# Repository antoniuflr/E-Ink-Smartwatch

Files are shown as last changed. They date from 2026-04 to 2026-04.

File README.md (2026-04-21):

# InkTime Smartwatch
The low-powered open-source e-paper watch.

## Final Assembly
<p align="center">
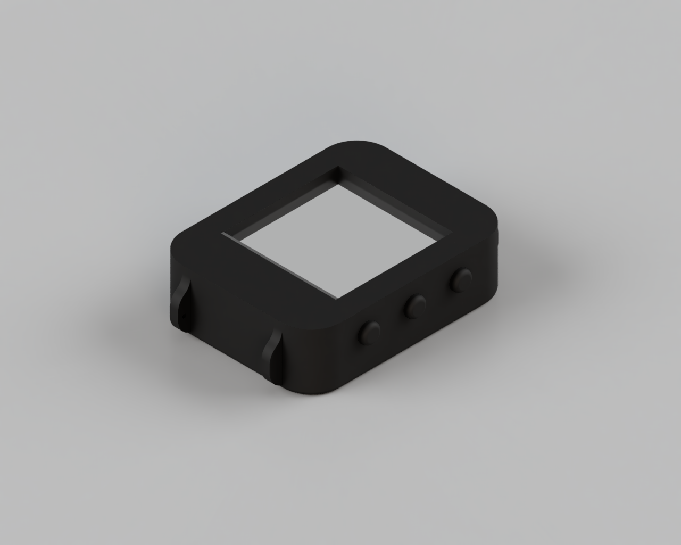
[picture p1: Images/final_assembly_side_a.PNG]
Final assembly side A
  
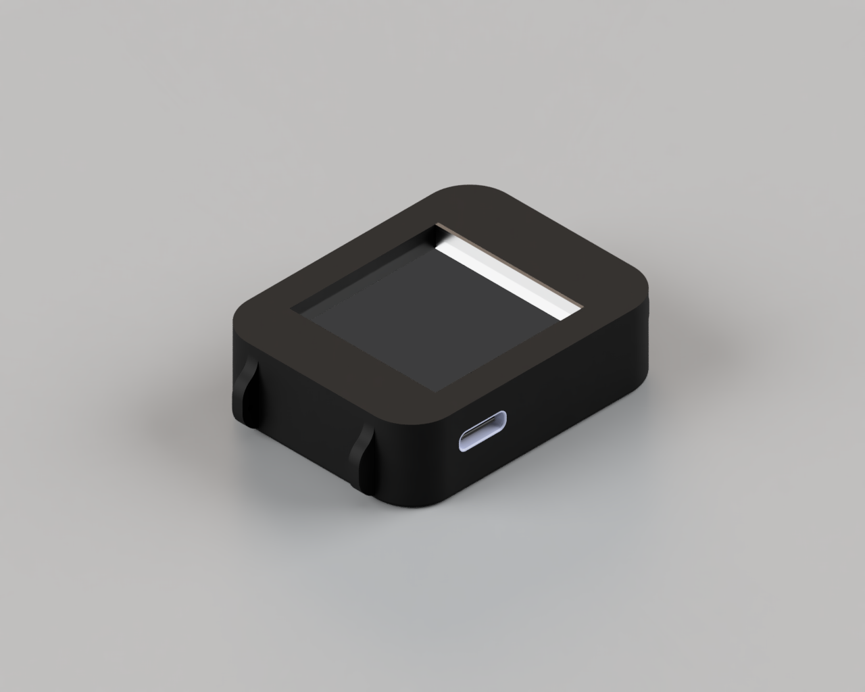
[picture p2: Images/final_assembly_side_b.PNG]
Final assembly side B
  
</p>

## Block Diagram
<p align="center">
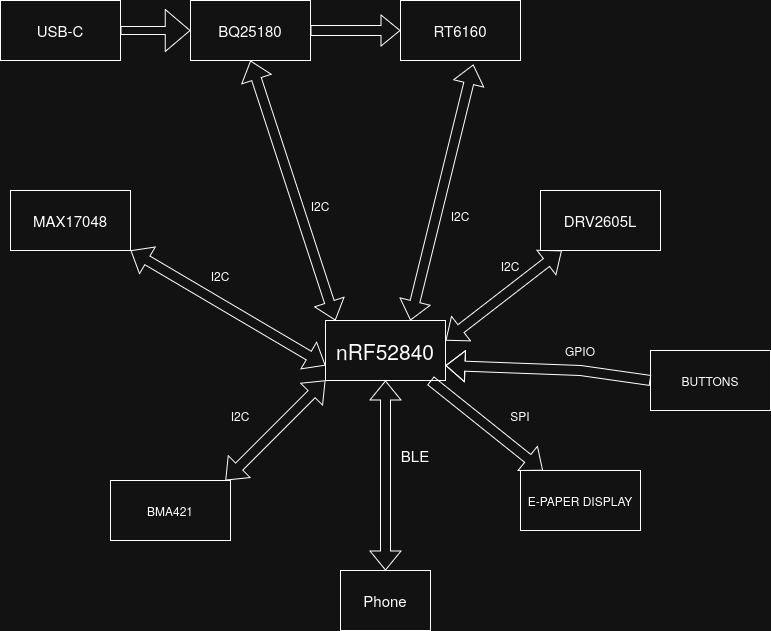
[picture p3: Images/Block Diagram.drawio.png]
InkTime block diagram
  
</p>

## Bill of Materials
| Ref | Componenta | Valoare | JLC Parts | Datasheet |
|-----|---|---|---|---|
| U1 | nRF52840 | $5.14 | [JLC](https://jlcpcb.com/parts/componentSearch?searchTxt=nRF52840-QF) | [DS](https://jlcpcb.com/api/file/downloadByFileSystemAccessId/8589839228197629952) |
| J1 | 503480-2400 | $0.84 | [JLC](https://jlcpcb.com/partdetail/MOLEX-5034802400/C122434) | [DS](https://www.molex.com/content/dam/molex/molex-dot-com/products/automated/en-us/salesdrawingpdf/503/503480/5034802400_sd.pdf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) |
| IC1 | BQ25180YBGR | $2.01 | [JLC](https://jlcpcb.com/partdetail/TexasInstruments-BQ25180YBGR/C3682423) | [DS](https://www.ti.com/cn/lit/gpn/bq25180) |
| X2 | FC-135_32.7680KA-A3 | $0.2677 | [JLC](https://jlcpcb.com/partdetail/SeikoEpson-FC_135_32_7680KAA3/C2650472) | [DS](https://jlcpcb.com/partdetail/SeikoEpson-FC_135_32_7680KAA3/C2650472) |
| Q1 | DMG2305UX-7 | $0.10 | [JLC](https://jlcpcb.com/partdetail/DiodesIncorporated-DMG2305UX7/C150470) | [DS](https://jlcpcb.com/api/file/downloadByFileSystemAccessId/8560079443617075200) |
| D5 | MBR0530 | $0.03 | [JLC](https://jlcpcb.com/partdetail/78464-MBR0530/C77336) | [DS](https://jlcpcb.com/api/file/downloadByFileSystemAccessId/8586175081181818880) |
| IC9 | RT6160 | $0.56 | [JLC](https://jlcpcb.com/partdetail/RichtekTech-RT6160AWSC/C7065276) | [DS](https://jlcpcb.com/api/file/downloadByFileSystemAccessId/8600398231234883584) |
| L2 | RC0402JR-070RL | $0.01 | [JLC](https://jlcpcb.com/partdetail/YAGEO-RC0402JR070RL/C60485) | [DS](https://jlcpcb.com/api/file/downloadByFileSystemAccessId/8717146932348461056) |
| J4 | KH-TYPE-C-16P | $0.08 | [JLC](https://jlcpcb.com/partdetail/Shenzhen_KinghelmElec-KH_TYPE_C16P/C709357) | [DS](https://jlcpcb.com/api/file/downloadByFileSystemAccessId/8588905154556923904) |
| SWD | TC2030-IDC | $100.26 | [JLC](https://jlcpcb.com/partdetail/MicrochipTech-TC2030_CLIP3PACK/C5444772) | [DS](https://www.lcsc.com/datasheet/lcsc_datasheet_2403201318_Microchip-Tech-TC2030-CLIP-3PACK_C5444772.pdf) |
| U3 | MAX17048G-T10 | $2.44 | [JLC](https://jlcpcb.com/partdetail/2777647-MAX17048GT10/C2682616) | [DS](https://jlcpcb.com/api/file/downloadByFileSystemAccessId/8588907428524003328) |
| D3 | USBLC6-2SC6Y | $0.24 | [JLC](https://jlcpcb.com/partdetail/STMicroelectronics-USBLC62SC6Y/C2969755) | [DS](https://jlcpcb.com/api/file/downloadByFileSystemAccessId/8603165824304111616) |
| L3 | RC0402JR-070RL | $0.01 | [JLC](https://jlcpcb.com/partdetail/YAGEO-RC0402JR070RL/C60485) | [DS](https://jlcpcb.com/api/file/downloadByFileSystemAccessId/8717146932348461056) |
| X1 | NX2016SA-32MHZ-EXS00A-CS11336 | $9.04 | [JLC](https://jlcpcb.com/partdetail/NDK-NX2016SA_32MHZ_EXS00ACS11336/C6134317) | [DS](https://jlcpcb.com/api/file/downloadByFileSystemAccessId/8603064888214908928) |
| ANT1 | 2450AT18B100E | $1.03 | [JLC](https://jlcpcb.com/partdetail/JohansonDielectrics-2450AT18B100E/C2917717) | [DS](https://jlcpcb.com/api/file/downloadByFileSystemAccessId/8588940948130156544) |
| Q3 | SI1308EDL-T1-GE3 | $0.18 | [JLC](https://jlcpcb.com/partdetail/VishayIntertech-SI1308EDL_T1GE3/C469327) | [DS](https://jlcpcb.com/api/file/downloadByFileSystemAccessId/8588884784742846464) |
| IC2 | DRV2605YZFR | $1.31 | [JLC](https://jlcpcb.com/partdetail/TexasInstruments-DRV2605YZFR/C81079) | [DS](https://www.ti.com/cn/lit/gpn/drv2605) |
| D2 | MBR0530 | $0.03 | [JLC](https://jlcpcb.com/partdetail/78464-MBR0530/C77336) | [DS](https://jlcpcb.com/api/file/downloadByFileSystemAccessId/8586175081181818880) |
| IC3 | BMA423 | $11.30 | [JLC](https://jlcpcb.com/partdetail/BoschSensortec-BMA423/C189517) | [DS](https://jlcpcb.com/api/file/downloadByFileSystemAccessId/8588894317147017216) |
| L7 | MLP2016SR47MT0S1 | $0.10 | [JLC](https://jlcpcb.com/partdetail/TDK-MLP2016SR47MT0S1/C87545) | [DS](https://jlcpcb.com/api/file/downloadByFileSystemAccessId/8588933367512879104) |
| L5 | 744043680 | $9.53 | [JLC](https://jlcpcb.com/partdetail/WurthElektronik-744043680/C2045671) | [DS](https://www.we-online.com/components/products/datasheet/744043680.pdf) |
| D4 | MBR0530 | $0.03 | [JLC](https://jlcpcb.com/partdetail/78464-MBR0530/C77336) | [DS](https://jlcpcb.com/api/file/downloadByFileSystemAccessId/8586175081181818880) |

## Hardware Overview
- `nRF52840 (U1)`: main MCU; handles BLE, USB, timekeeping, button logic, display refresh, and power-state control.
- `BQ25180 (IC1)`: LiPo charger and power-path manager; takes `VBUS` from USB-C, charges the battery, and exposes status on `I2C` plus `PMIC_INT`.
- `RT6160 (IC9)`: buck-boost regulator; converts the charger `SYS/VREG` rail into the stable `3V3` rail used by the digital system.
- `BMA421 IMU (IC3 schematic value)`: accelerometer/pedometer connected over `I2C`; `INT1` and `INT2` wake the MCU on motion and step events.
- `MAX17048 (U3)`: fuel gauge connected to raw `VBAT`; reports battery state over `I2C` and raises `ALERT` on low-battery thresholds.
- `DRV2605L (IC2)`: haptic driver on `I2C`; enabled by `HAPTIC_EN` and drives the vibration motor through `OUT+` and `OUT-`.
- `E-paper display (J1)`: connected through `SPI` (`SCK`, `MOSI`, `CS`) plus `DC`, `RST`, and `BUSY`; uses a dedicated switched rail so the panel can be fully turned off between updates.
- `USB-C + ESD (J4 + D3)`: provides `VBUS` power, USB `D+ / D-`, and surge protection for the MCU USB interface.
- `Debug + bring-up`: Tag-Connect `TC2030` exposes `SWDIO`, `SWDCLK`, and `RESET` for flashing and recovery.
- `Power strategy`: `USB-C 5V -> BQ25180 -> RT6160 -> 3V3`; the watch stays in low-power sleep most of the time, wakes on RTC/buttons/interrupts, and uses e-paper partial refreshes to keep average power low.
- `Communication`: shared `I2C` bus for PMIC, regulator, IMU, fuel gauge, and haptic driver; `SPI` for the display; `BLE` for the phone link.

## Exploded Assembly
<p align="center">
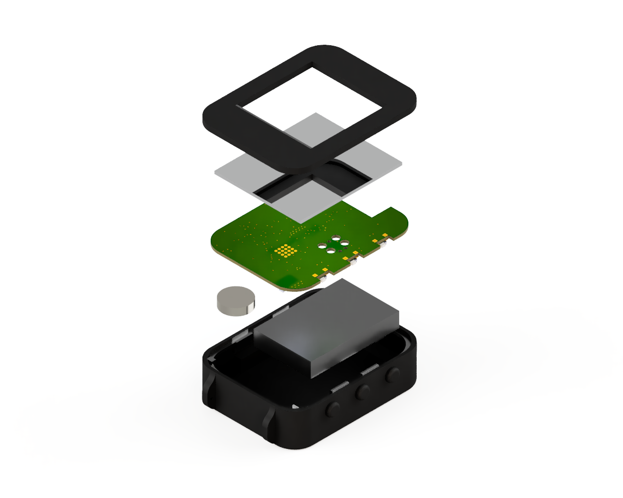
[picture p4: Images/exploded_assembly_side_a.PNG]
Exploded assembly side A
  
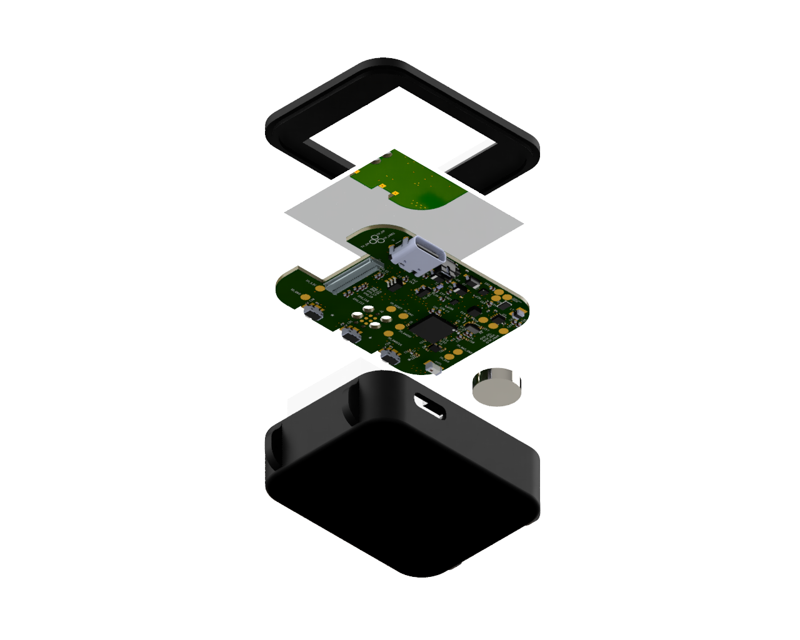
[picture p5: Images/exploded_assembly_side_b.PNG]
Exploded assembly side B
  
</p>

## nRF52840 Pin Mapping
| nRF52840 Pin | Signal | Component | Interface |
|---|---|---|---|
| P0.00/XL1 | XL1 | Crystal X2 (32.768kHz) | XTAL |
| P0.01/XL2 | XL2 | Crystal X2 (32.768kHz) | XTAL |
| P0.02/AIN0 | SCK | E-Paper (J1 FPC) | SPI SCK |
| P0.03/AIN1 | MOSI | E-Paper (J1 FPC) | SPI MOSI |
| P0.05/AIN3 | EPD_CS | E-Paper (J1 FPC) | SPI CS |
| P0.06 | SDA | BMA421, BQ25180, RT6160, MAX17048, DRV2605 | I2C SDA |
| P0.07 | SCL | BMA421, BQ25180, RT6160, MAX17048, DRV2605 | I2C SCL |
| P0.08 | IMU_INT1 | BMA421 | GPIO Input |
| P1.08 | IMU_INT2 | BMA421 | GPIO Input |
| P0.10/NFC2 | ALERT | MAX17048 | GPIO Input |
| P0.11 | PMIC_INT | BQ25180 | GPIO Input |
| P0.12 | HAPTIC_EN | DRV2605 | GPIO Output |
| P0.13 | SW_UP | Up button | GPIO Input |
| P0.14 | SW_ENT | Enter button | GPIO Input |
| P0.15 | EPD_DC | E-Paper (J1 FPC) | SPI DC |
| P0.16 | EPD_RST | E-Paper (J1 FPC) | GPIO Output |
| P0.17 | EPD_BUSY | E-Paper (J1 FPC) | GPIO Input |
| P0.18/RESET | RESET | TC2030-IDC | SWD / GPIO |
| P1.02 | SW_DN | Down button | GPIO Input |
| VBUS | VBUS | USB-C (J4) | Power |
| D- | D- | USB-C (J4) / USBLC6 | USB |
| D+ | D+ | USB-C (J4) / USBLC6 | USB |
| SWDCLK | SWDCLK | TC2030-IDC | SWD |
| SWDIO | SWDIO | TC2030-IDC | SWD |
| ANT | RF | 2450AT18B100E antenna | RF |

## PCB Views
<p align="center">
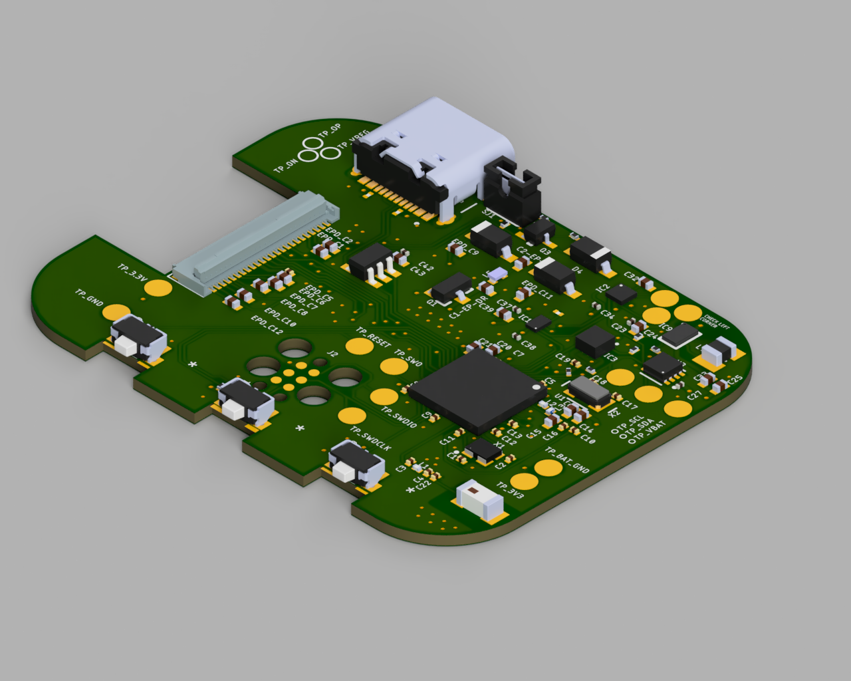
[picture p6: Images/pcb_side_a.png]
PCB side A
  
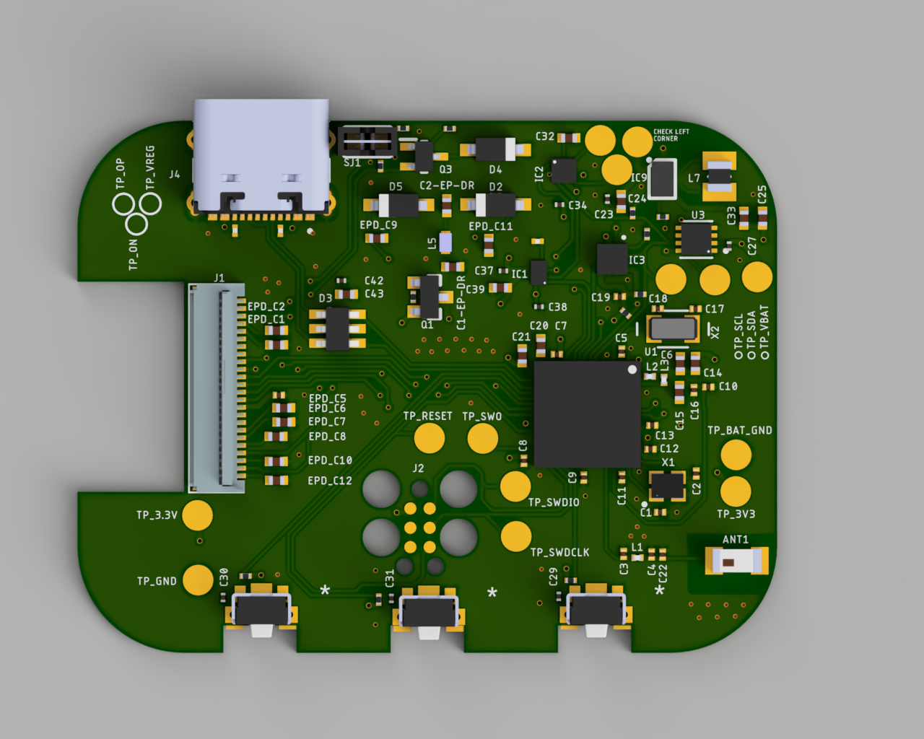
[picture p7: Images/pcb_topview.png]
PCB top view
  
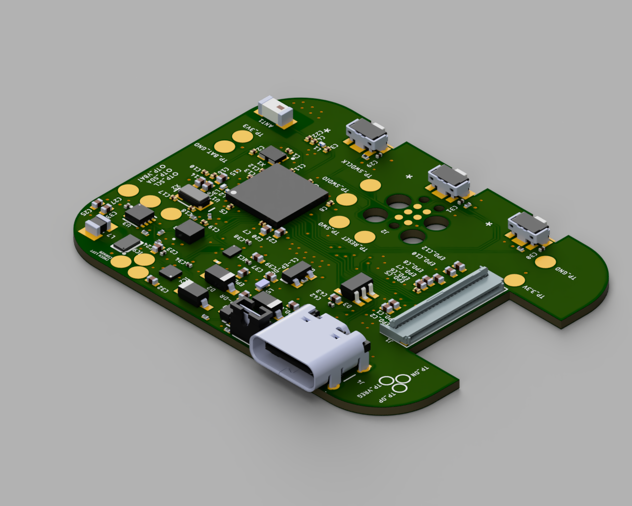
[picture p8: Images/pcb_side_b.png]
PCB side B
  
</p>

## Log Journal
- Grouping IC's with their respective passive components.
- Placing them so ratsnest is as straight as possible on the board.
- Route critical signal first.
- Route power.
- Route rest.

Clean ERC. Ignored micro-via errors in DRC because without them routing the BGA would have been impossible.

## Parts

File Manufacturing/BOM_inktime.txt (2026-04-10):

Partlist exported from Fusion Hub: chec   Project: InkTime  Board: inktime_schematic at 4/10/2026 11:14 PM

Qty Value                                                   Device                                                                       Package                                                                                                                Parts                                                                                                                      Description                                                                                                               ARROW_PART_NUMBER ARROW_PRICE-STOCK                                                                                AVAILABILITY CATEGORY CHECK_PRICES                                                                       COPYRIGHT                                                DATASHEET                                                 DESCRIPTION                                                                                                                                                                         DIGI-KEY_PART_NUMBER_1                    DIGI-KEY_PART_NUMBER_2 DIGI-KEY_PART_NUMBER_3                              FREQUENCY  FREQUENCY_STABILITY HEIGHT  JLCPCB LOAD_CAPACITANCE MANUFACTURER                                                     MANUFACTURER_NAME   MANUFACTURER_PART_NUMBER MF                 MOUSER_PART_NUMBER MOUSER_PRICE-STOCK                                                                                           MP                                                                                                       MPN                 OPERATING_TEMPERATURE PACKAGE                     PACKAGE_SIZE  PACKAGE_TYPE  PART_STATUS                  POPULARITY PRICE PROD_ID    PURCHASE-URL                                                                                                                               ROHS      SERIES SNAPEDA_LINK                                                                                                                                    SUBCATEGORY THERMALLOSS TOLERANCE                                                                           TP_SIGNAL_NAME TYPE       VALUE             
1                                                           ESP32_C6_LIBRARY_7_JUMPER_SJ                                                 ESP32_C6_LIBRARY_7_JUMPER_SJ                                                                                           SJ1                                                                                                                        SMD solder JUMPER                                                                                                                                                                                                                                                                                                                                                                                                                                                                                                                                                                                                                                                                                                                                                                                                                                                                                                                                                                                                                                                                                                                                                                                                                                                                                                                                         3                                                                                                                                                                                                                                                                                                                                                                                                                                                                                               
3   0                                                       CPF0201D7K68C1_CPF0201D7K68C1                                                CPF0201D7K68C1_0201                                                                                                    R2, R3, R4                                                                                                                 7.68k 0201 Thin Film Surface Mount Fixed Resistor +/-0.5% 0.031W CPF0201D7K68C1                                                                                                                                                                                                                                                                                                                                                                                                                                                                                                                                                                                                                                                                                                                                                                                                                                                                                                                                                                                                                                                                                                                                                                                                                                                                                                                                                                                                                                                                                                                                                                                                                                                                                                                                                                           
4   0.1µF                                                   GRM011R60J152KE01L_2_GRM011R60J152KE01L                                      GRM011R60J152KE01L_2_CAPC0201X13N                                                                                      C23, C27, C34, C42                                                                                                         Check availability                                                                                                                                                                                                                           In Stock              https://www.snapeda.com/parts/GRM011R60J152KE01L/Murata/view-part/?ref=eda                                                                                                                                                                                  SMD Capacitor X5R(EIA) with Capacitance: 1500pF Tol. 10%. Rated Voltage: 6.3Vdc                                                                                                                                                                                                                                                                                                                                                 Murata                                                                                                                                             GRM011R60J152KE01L                                                                                                                                 0201 Murata                                                                                     None                                                                                                                                                                         https://www.snapeda.com/parts/GRM011R60J152KE01L/Murata/view-part/?ref=snap                                                                                                                                                                                                                             
1   0.1µF/50v                                               NORDIC_NRF_3_CAPACITOR_0201_L                                                NORDIC_NRF_3_RESC0201_L                                                                                                EPD_C5                                                                                                                     Generic chip capacitor                                                                                                                                                                                                                                                                                                                                                                                                                                                                                                                                                                                                                                                                                                                                                                                                                                                                                                                                                                                                                                                                                                                                                                                                                                                                                                                                                                                                                                                                                                                                                                                                                                                                                                                                                                                                                                    
1   0.47                                                    CPF0201D7K68C1_CPF0201D7K68C1                                                CPF0201D7K68C1_0201                                                                                                    R1_EP_DR                                                                                                                   7.68k 0201 Thin Film Surface Mount Fixed Resistor +/-0.5% 0.031W CPF0201D7K68C1                                                                                                                                                                                                                                                                                                                                                                                                                                                                                                                                                                                                                                                                                                                                                                                                                                                                                                                                                                                                                                                                                                                                                                                                                                                                                                                                                                                                                                                                                                                                                                                                                                                                                                                                                                           
1   1.0µF                                                   NORDIC_NRF_3_CAPACITOR_0402_L                                                NORDIC_NRF_3_RESC0402_L                                                                                                C15                                                                                                                        Generic chip capacitor                                                                                                                                                                                                                                                                                                                                                                                                                                                                                                                                                                                                                                                                                                                                                                                                                                                                                                                                                                                                                                                                                                                                                                                                                                                                                                                                                                                                                                                                                                                                                                                                                                                                                                                                                                                                                                    
5   100nF                                                   NORDIC_NRF_3_CAPACITOR_0201_L                                                NORDIC_NRF_3_RESC0201_L                                                                                                C5, C7, C8, C12, C19                                                                                                       Generic chip capacitor                                                                                                                                                                                                                                                                                                                                                                                                                                                                                                                                                                                                                                                                                                                                                                                                                                                                                                                                                                                                                                                                                                                                                                                                                                                                                                                                                                                                                                                                                                                                                                                                                                                                                                                                                                                                                                    
1   100pF                                                   NORDIC_NRF_3_CAPACITOR_0201_L                                                NORDIC_NRF_3_RESC0201_L                                                                                                C11                                                                                                                        Generic chip capacitor                                                                                                                                                                                                                                                                                                                                                                                                                                                                                                                                                                                                                                                                                                                                                                                                                                                                                                                                                                                                                                                                                                                                                                                                                                                                                                                                                                                                                                                                                                                                                                                                                                                                                                                                                                                                                                    
2   10K                                                     CPF0201D7K68C1_CPF0201D7K68C1                                                CPF0201D7K68C1_0201                                                                                                    R2_EP_DR, R_PWR_EPD                                                                                                        7.68k 0201 Thin Film Surface Mount Fixed Resistor +/-0.5% 0.031W CPF0201D7K68C1                                                                                                                                                                                                                                                                                                                                                                                                                                                                                                                                                                                                                                                                                                                                                                                                                                                                                                                                                                                                                                                                                                                                                                                                                                                                                                                                                                                                                                                                                                                                                                                                                                                                                                                                                                           
1   10K                                                     ERA-1AEB3401C_CPF0201D7K68C1                                                 ERA-1AEB3401C_0201                                                                                                     R9                                                                                                                         7.68k 0201 Thin Film Surface Mount Fixed Resistor +/-0.5% 0.031W CPF0201D7K68C1                                                                                                                                                                                                                                                                                                                                                                                                                                                                                                                                                                                                                                                                                                                                                                                                                                                                                                                                                                                                                                                                                                                                                                                                                                                                                                                                                                                                                                                                                                                                                                                                                                                                                                                                                                           
3   10k                                                     CPF0201D7K68C1_CPF0201D7K68C1                                                CPF0201D7K68C1_0201                                                                                                    R5, R7, R8                                                                                                                 7.68k 0201 Thin Film Surface Mount Fixed Resistor +/-0.5% 0.031W CPF0201D7K68C1                                                                                                                                                                                                                                                                                                                                                                                                                                                                                                                                                                                                                                                                                                                                                                                                                                                                                                                                                                                                                                                                                                                                                                                                                                                                                                                                                                                                                                                                                                                                                                                                                                                                                                                                                                           
3   10µF                                                    NORDIC_NRF_3_CAPACITOR_0402_L                                                NORDIC_NRF_3_RESC0402_L                                                                                                C1-EP-DR, C24, C39                                                                                                         Generic chip capacitor
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

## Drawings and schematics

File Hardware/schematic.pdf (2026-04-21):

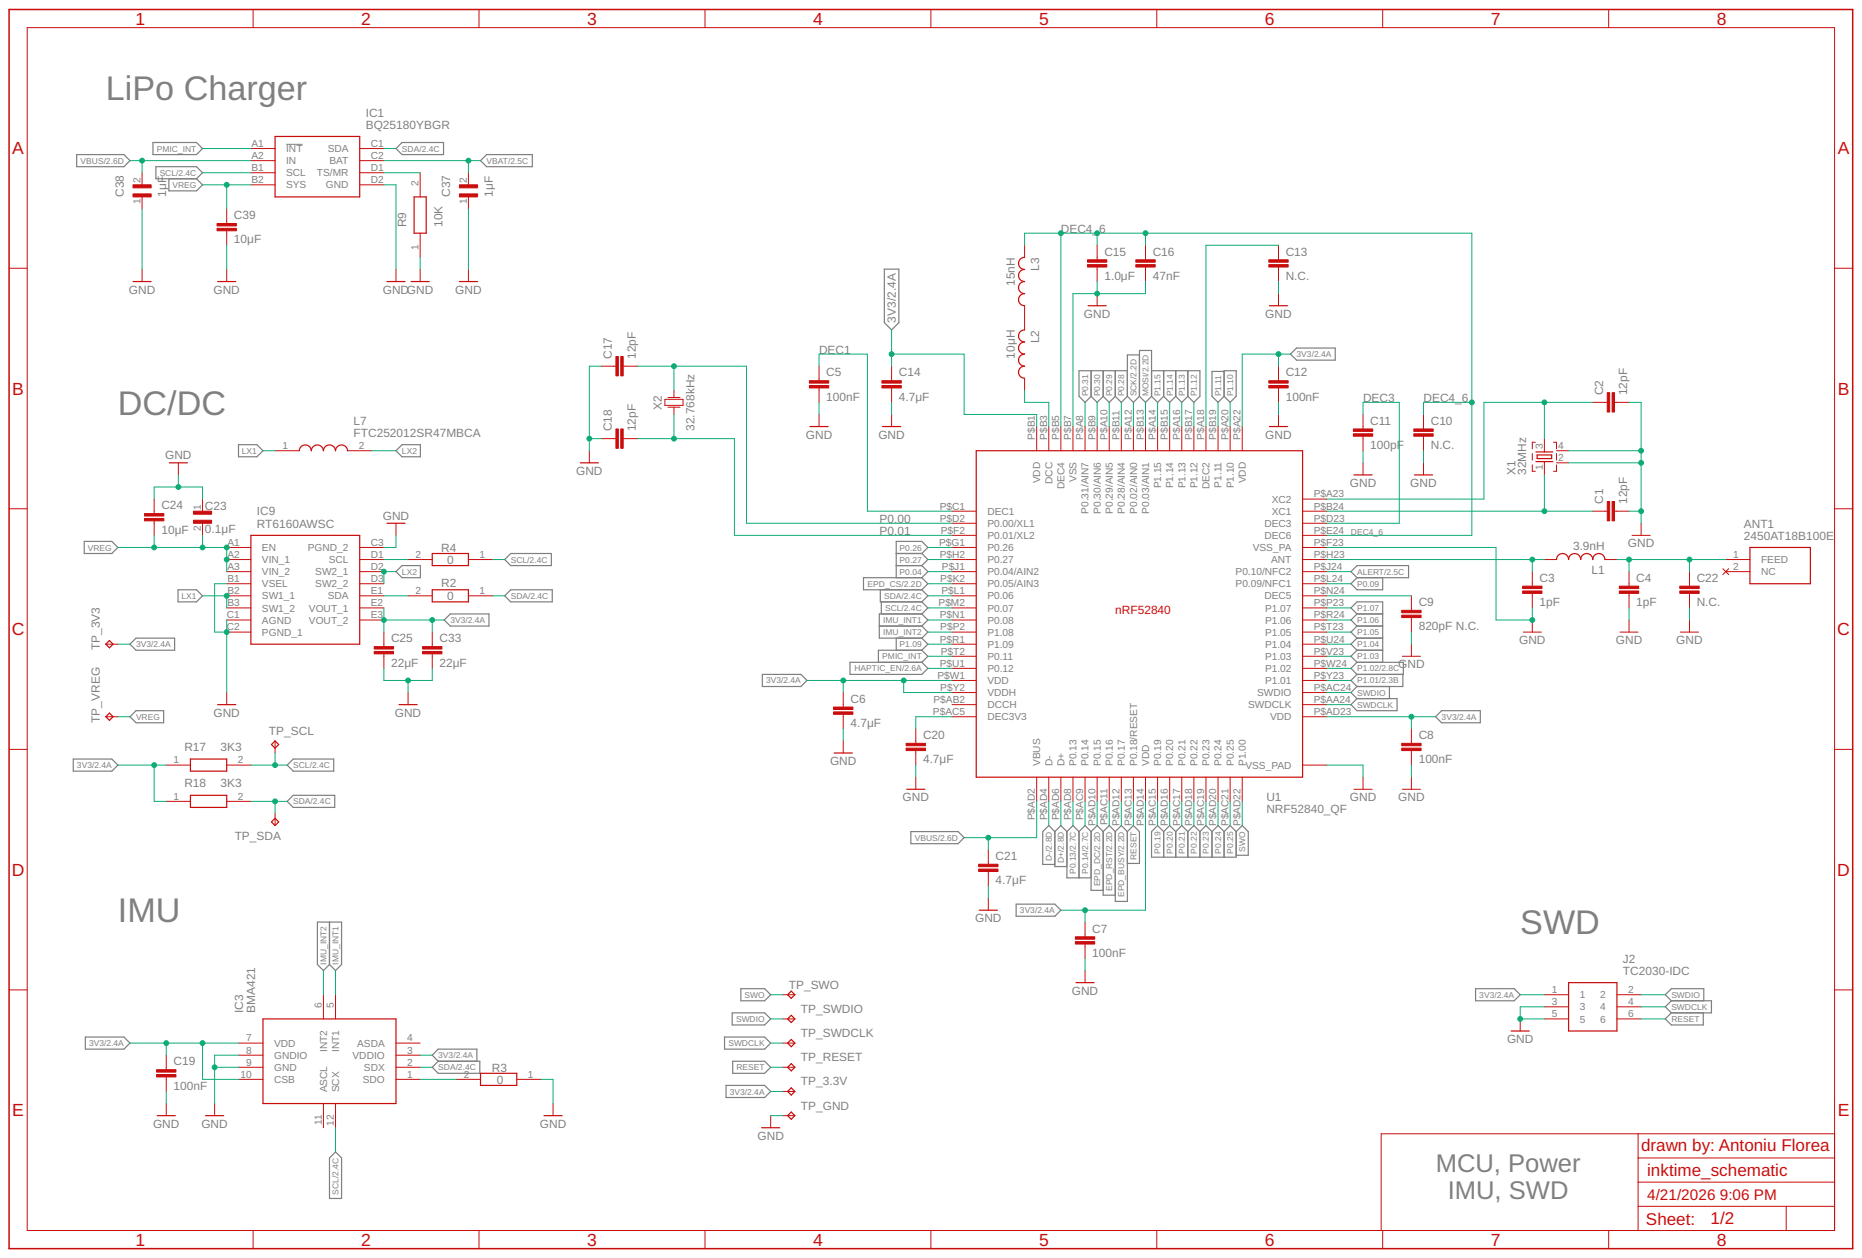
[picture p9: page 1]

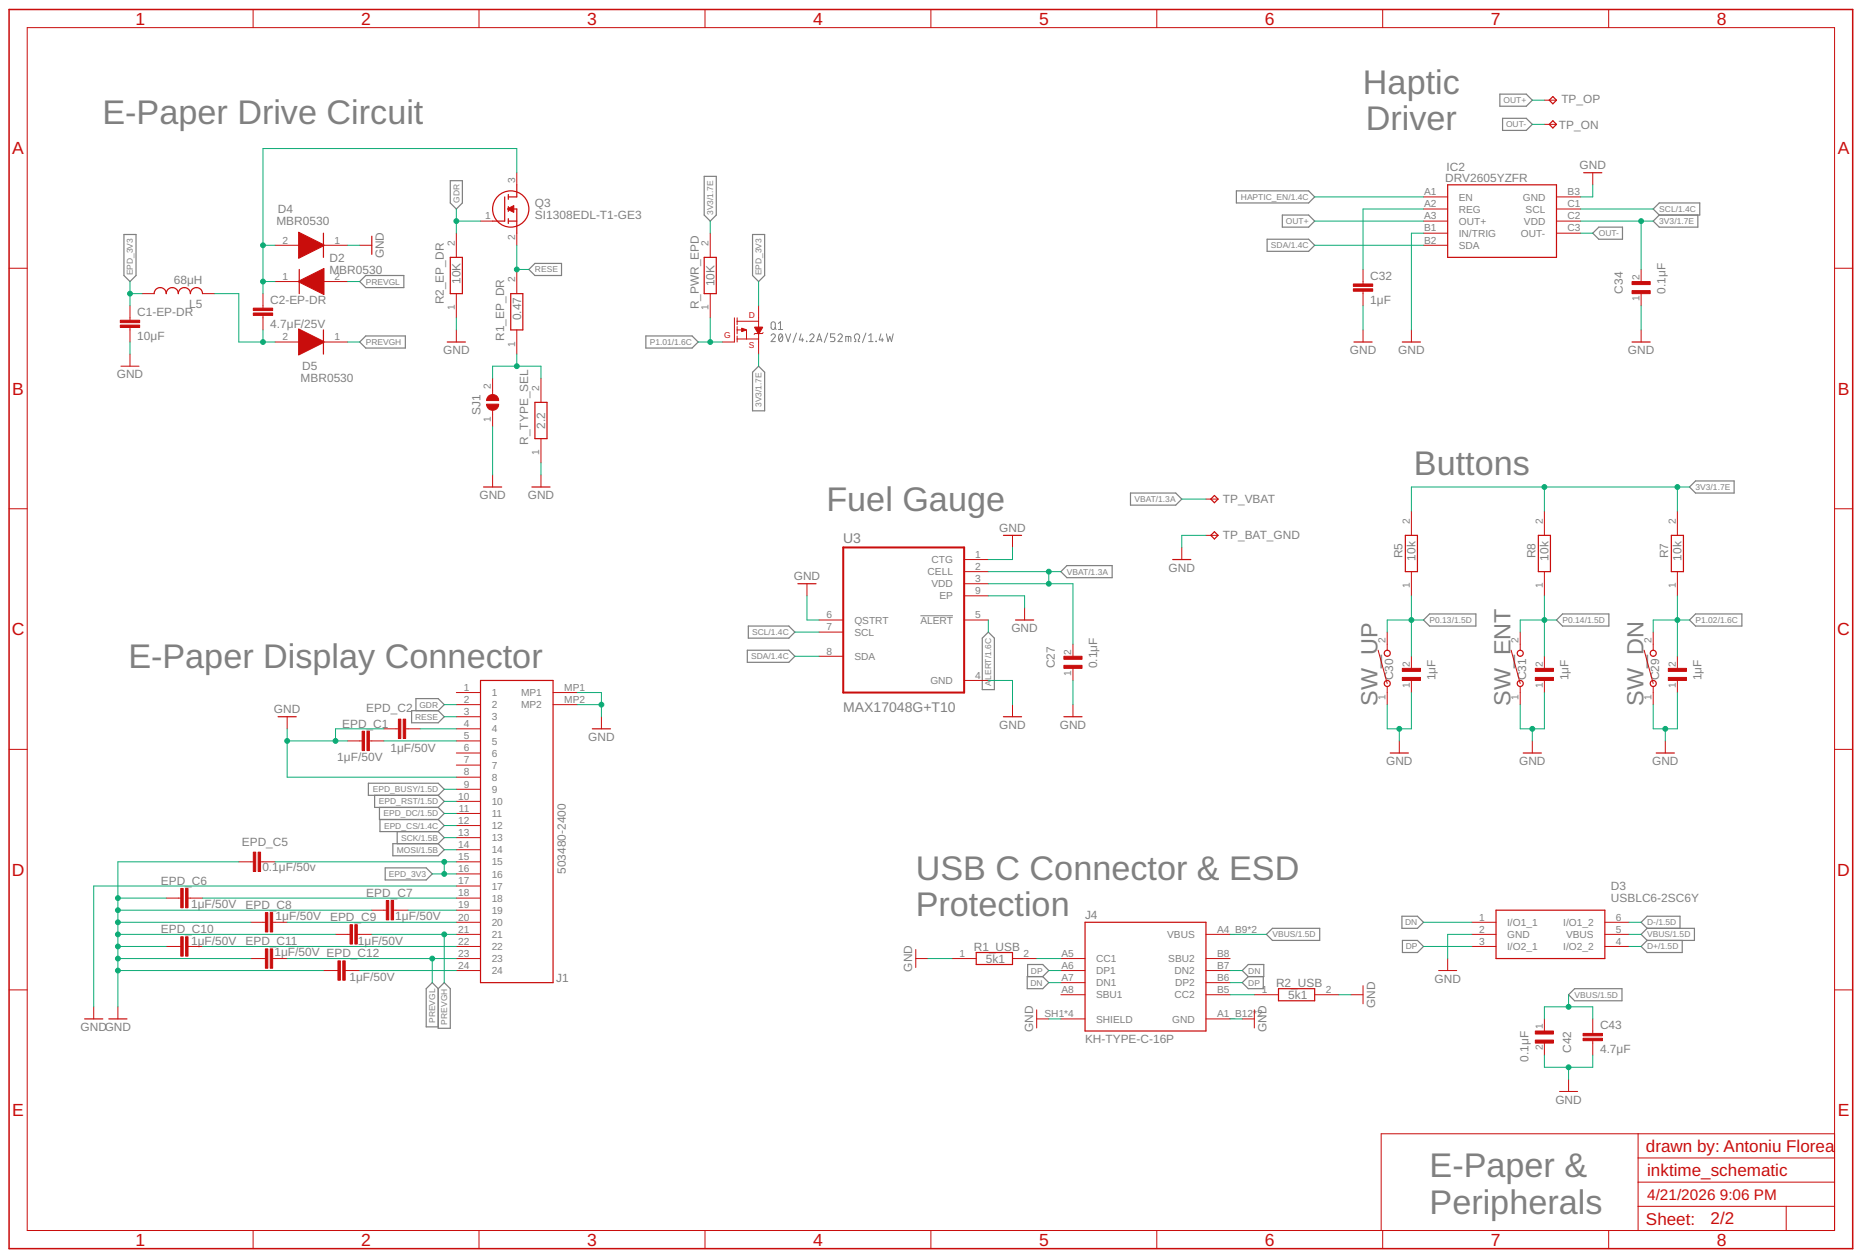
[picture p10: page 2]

EPD_C7 18

EPD_C8 | 19

1μF/50V EPD_C12 | 23

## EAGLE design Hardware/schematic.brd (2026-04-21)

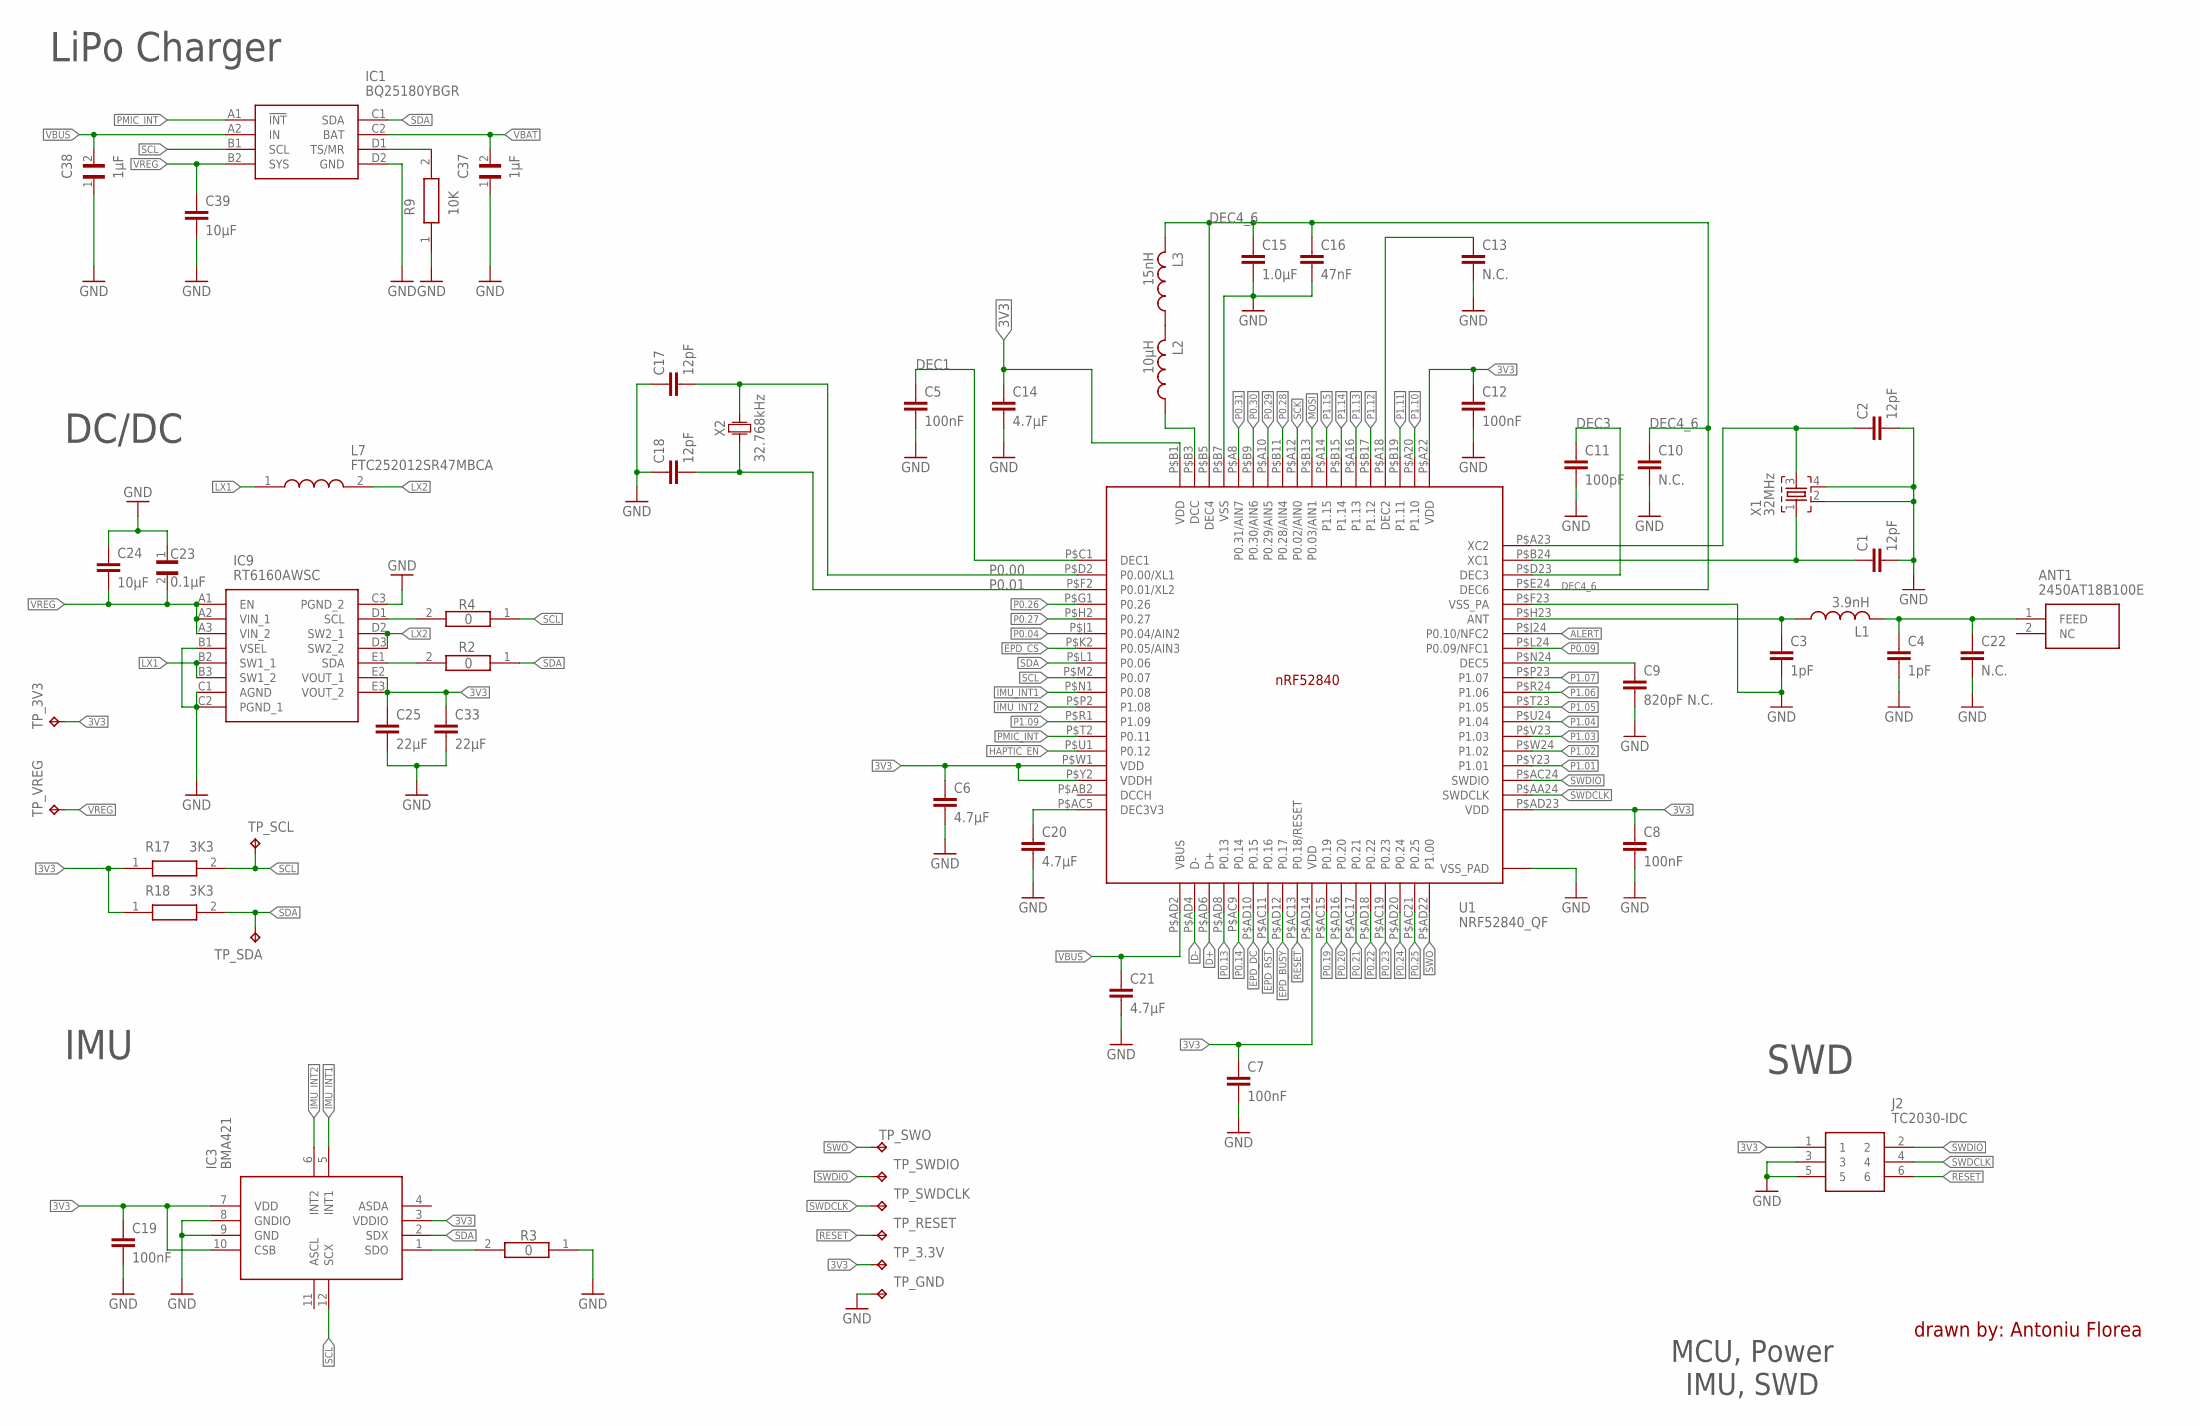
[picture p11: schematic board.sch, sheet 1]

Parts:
ANT1: 2450AT18B100E; 2450AT18B100E_ANTC3216X140N
C1, C2, C17, C18: 12pF; NORDIC_NRF_3_RESC0201_L
C3, C4: 1pF; NORDIC_NRF_3_RESC0201_L
C5, C7, C8, C12, C19: 100nF; NORDIC_NRF_3_RESC0201_L
C6, C14, C20, C21: 4.7μF; NORDIC_NRF_3_RESC0402_L
C9: 820pF N.C.; NORDIC_NRF_3_RESC0201_L
C10, C13, C22: N.C.; NORDIC_NRF_3_RESC0201_L
C11: 100pF; NORDIC_NRF_3_RESC0201_L
C15: 1.0μF; NORDIC_NRF_3_RESC0402_L
C16: 47nF; NORDIC_NRF_3_RESC0201_L
C23: 0.1μF; GRM011R60J152KE01L_2_CAPC0201X13N
C24, C39: 10μF; NORDIC_NRF_3_RESC0402_L
C25, C33: 22μF; NORDIC_NRF_3_RESC0402_L
C37, C38: 1μF; GRM011R60J152KE01L_2_CAPC0201X13N
IC1: BQ25180YBGR; BQ25180YBGR_BGA8C40P2X4_100X155X50
IC3: BMA421; BMA423_BMA423
IC9: RT6160AWSC; RT6160AWSC_BGA15C40P3X5_140X230X60
J2: TC2030-IDC; TC2030-IDC_TC2030IDC
L1: 3.9nH; NORDIC_NRF_2_RESC0201_L
L2: 10μH; NORDIC_NRF_2_RESC0201_L
L3: 15nH; NORDIC_NRF_2_RESC0201_L
L7: FTC252012SR47MBCA; MLP2016SR47MT0S1_INDC2016X100N
R2, R3, R4: 0; CPF0201D7K68C1_0201
R9: 10K; ERA-1AEB3401C_0201
R17, R18: 3K3; CPF0201D7K68C1_0201
TP_3.3V, TP_3V3: HECTOR_WATCH_1_TPTP20R; HECTOR_WATCH_1_TP20R
TP_GND: HECTOR_WATCH_1_TPTP20R; HECTOR_WATCH_1_TP20R
TP_RESET: HECTOR_WATCH_1_TPTP20R; HECTOR_WATCH_1_TP20R
TP_SCL: HECTOR_WATCH_1_TPTP20R; HECTOR_WATCH_1_TP20R
TP_SDA: HECTOR_WATCH_1_TPTP20R; HECTOR_WATCH_1_TP20R
TP_SWDCLK: HECTOR_WATCH_1_TPTP20R; HECTOR_WATCH_1_TP20R
TP_SWDIO: HECTOR_WATCH_1_TPTP20R; HECTOR_WATCH_1_TP20R
TP_SWO: HECTOR_WATCH_1_TPTP20R; HECTOR_WATCH_1_TP20R
TP_VREG: HECTOR_WATCH_1_TPTP20R; HECTOR_WATCH_1_TP20R
U1: NRF52840_QF; NORDIC_NRF_4_AQFN50P700X700X85_HS-74N
X1: 32MHz; NORDIC_NRF_BT-XTAL_2016_N
X2: 32.768kHz; XTAL330X1051X90N

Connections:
3V3: C6.1, C7.1, C8.1, C12.1, C14.1, C19.1, C25.1, C33.1, IC3.3 (VDDIO), IC3.7 (VDD), IC3.10 (CSB), IC9.E2 (VOUT_1), IC9.E3 (VOUT_2), J2.1, R17.1, R18.1, TP_3.3V.TP, TP_3V3.TP, U1.P$A22 (VDD), U1.P$AD14 (VDD), U1.P$AD23 (VDD), U1.P$B1 (VDD), U1.P$W1 (VDD), U1.P$Y2 (VDDH); also elsewhere on the board
ALERT: U1.P$J24 (P0.10/NFC2); also elsewhere on the board
D+: U1.P$AD6 (D+); also elsewhere on the board
D-: U1.P$AD4 (D-); also elsewhere on the board
DEC1: C5.1, U1.P$C1 (DEC1)
DEC3: C11.1, U1.P$D23 (DEC3)
DEC4_6: C10.1, C15.1, C16.1, L3.2, U1.P$B5 (DEC4), U1.P$E24 (DEC6)
EPD_BUSY: U1.P$AD12 (P0.17); also elsewhere on the board
EPD_CS: U1.P$K2 (P0.05/AIN3); also elsewhere on the board
EPD_DC: U1.P$AD10 (P0.15); also elsewhere on the board
EPD_RST: U1.P$AC11 (P0.16); also elsewhere on the board
GND: C1.2, C2.2, C3.2, C4.2, C5.2, C6.2, C7.2, C8.2, C9.2, C10.2, C11.2, C12.2, C13.2, C14.2, C15.2, C16.2, C17.1, C18.1, C19.2, C20.2, C21.2, C22.2, C23.1, C24.1, C25.2, C33.2, C37.1, C38.1, C39.2, IC1.D2 (GND), IC3.8 (GNDIO), IC3.9 (GND), IC9.B1 (VSEL), IC9.C1 (AGND), IC9.C2 (PGND_1), IC9.C3 (PGND_2), J2.3, J2.5, R3.1, R9.1, TP_GND.TP, U1.P$74 (VSS_PAD), U1.P$75 (VSS_PAD), U1.P$76 (VSS_PAD), U1.P$77 (VSS_PAD), U1.P$78 (VSS_PAD), U1.P$79 (VSS_PAD), U1.P$80 (VSS_PAD), U1.P$81 (VSS_PAD), U1.P$82 (VSS_PAD), U1.P$83 (VSS_PAD), U1.P$84 (VSS_PAD), U1.P$85 (VSS_PAD), U1.P$86 (VSS_PAD), U1.P$87 (VSS_PAD), U1.P$88 (VSS_PAD), U1.P$89 (VSS_PAD), U1.P$90 (VSS_PAD), U1.P$B7 (VSS), U1.P$F23 (VSS_PA), X1.2, X1.4; also elsewhere on the board
HAPTIC_EN: U1.P$U1 (P0.12); also elsewhere on the board
IMU_INT1: IC3.5 (INT1), U1.P$N1 (P0.08)
IMU_INT2: IC3.6 (INT2), U1.P$P2 (P1.08)
LX1: IC9.B2 (SW1_1), IC9.B3 (SW1_2), L7.1
LX2: IC9.D2 (SW2_1), IC9.D3 (SW2_2), L7.2
MOSI: U1.P$B13 (P0.03/AIN1); also elsewhere on the board
unnamed: C1.1, U1.P$B24 (XC1), X1.1
unnamed: C3.1, L1.1, U1.P$H23 (ANT)
unnamed: C2.1, U1.P$A23 (XC2), X1.3
unnamed: ANT1.1 (FEED), C4.1, C22.1, L1.2
unnamed: C9.1, U1.P$N24 (DEC5)
unnamed: C20.1, U1.P$AC5 (DEC3V3)
unnamed: L2.1, U1.P$B3 (DCC)
unnamed: L2.2, L3.1
unnamed: IC9.D1 (SCL), R4.2
unnamed: C13.1, U1.P$A18 (DEC2)
unnamed: IC1.D1 (TS/MR), R9.2
unnamed: IC9.E1 (SDA), R2.2
unnamed: IC3.1 (SDO), R3.2
P0.00: C17.2, U1.P$D2 (P0.00/XL1), X2.2
P0.01: C18.2, U1.P$F2 (P0.01/XL2), X2.1
P0.04: U1.P$J1 (P0.04/AIN2)
P0.09: U1.P$L24 (P0.09/NFC1)
P0.13: U1.P$AD8 (P0.13); also elsewhere on the board
P0.14: U1.P$AC9 (P0.14); also elsewhere on the board
P0.19: U1.P$AC15 (P0.19)
P0.20: U1.P$AD16 (P0.20)
P0.21: U1.P$AC17 (P0.21)
P0.22: U1.P$AD18 (P0.22)
P0.23: U1.P$AC19 (P0.23)
P0.24: U1.P$AD20 (P0.24)
P0.25: U1.P$AC21 (P0.25)
P0.26: U1.P$G1 (P0.26)
P0.27: U1.P$H2 (P0.27)
P0.28: U1.P$B11 (P0.28/AIN4)
P0.29: U1.P$A10 (P0.29/AIN5)
P0.30: U1.P$B9 (P0.30/AIN6)
P0.31: U1.P$A8 (P0.31/AIN7)
P1.01: U1.P$Y23 (P1.01); also elsewhere on the board
P1.02: U1.P$W24 (P1.02); also elsewhere on the board
P1.03: U1.P$V23 (P1.03)
P1.04: U1.P$U24 (P1.04)
P1.05: U1.P$T23 (P1.05)
P1.06: U1.P$R24 (P1.06)
P1.07: U1.P$P23 (P1.07)
P1.09: U1.P$R1 (P1.09)
P1.10: U1.P$A20 (P1.10)
P1.11: U1.P$B19 (P1.11)
P1.12: U1.P$B17 (P1.12)
P1.13: U1.P$A16 (P1.13)
P1.14: U1.P$B15 (P1.14)
P1.15: U1.P$A14 (P1.15)
PMIC_INT: IC1.A1 (!INT), U1.P$T2 (P0.11)
RESET: J2.6, TP_RESET.TP, U1.P$AC13 (P0.18/RESET)
SCK: U1.P$A12 (P0.02/AIN0); also elsewhere on the board
SCL: IC1.B1 (SCL), IC3.12 (SCX), R4.1, R17.2, TP_SCL.TP, U1.P$M2 (P0.07); also elsewhere on the board
SDA: IC1.C1 (SDA), IC3.2 (SDX), R2.1, R18.2, TP_SDA.TP, U1.P$L1 (P0.06); also elsewhere on the board
SWDCLK: J2.4, TP_SWDCLK.TP, U1.P$AA24 (SWDCLK)
SWDIO: J2.2, TP_SWDIO.TP, U1.P$AC24 (SWDIO)
SWO: TP_SWO.TP, U1.P$AD22 (P1.00)
VBAT: C37.2, IC1.C2 (BAT); also elsewhere on the board
VBUS: C21.1, C38.2, IC1.A2 (IN), U1.P$AD2 (VBUS); also elsewhere on the board
VREG: C23.2, C24.2, C39.1, IC1.B2 (SYS), IC9.A1 (EN), IC9.A2 (VIN_1), IC9.A3 (VIN_2), TP_VREG.TP

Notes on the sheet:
LiPo Charger
DC/DC
IMU
SWD
MCU, Power IMU, SWD
drawn by: Antoniu Florea

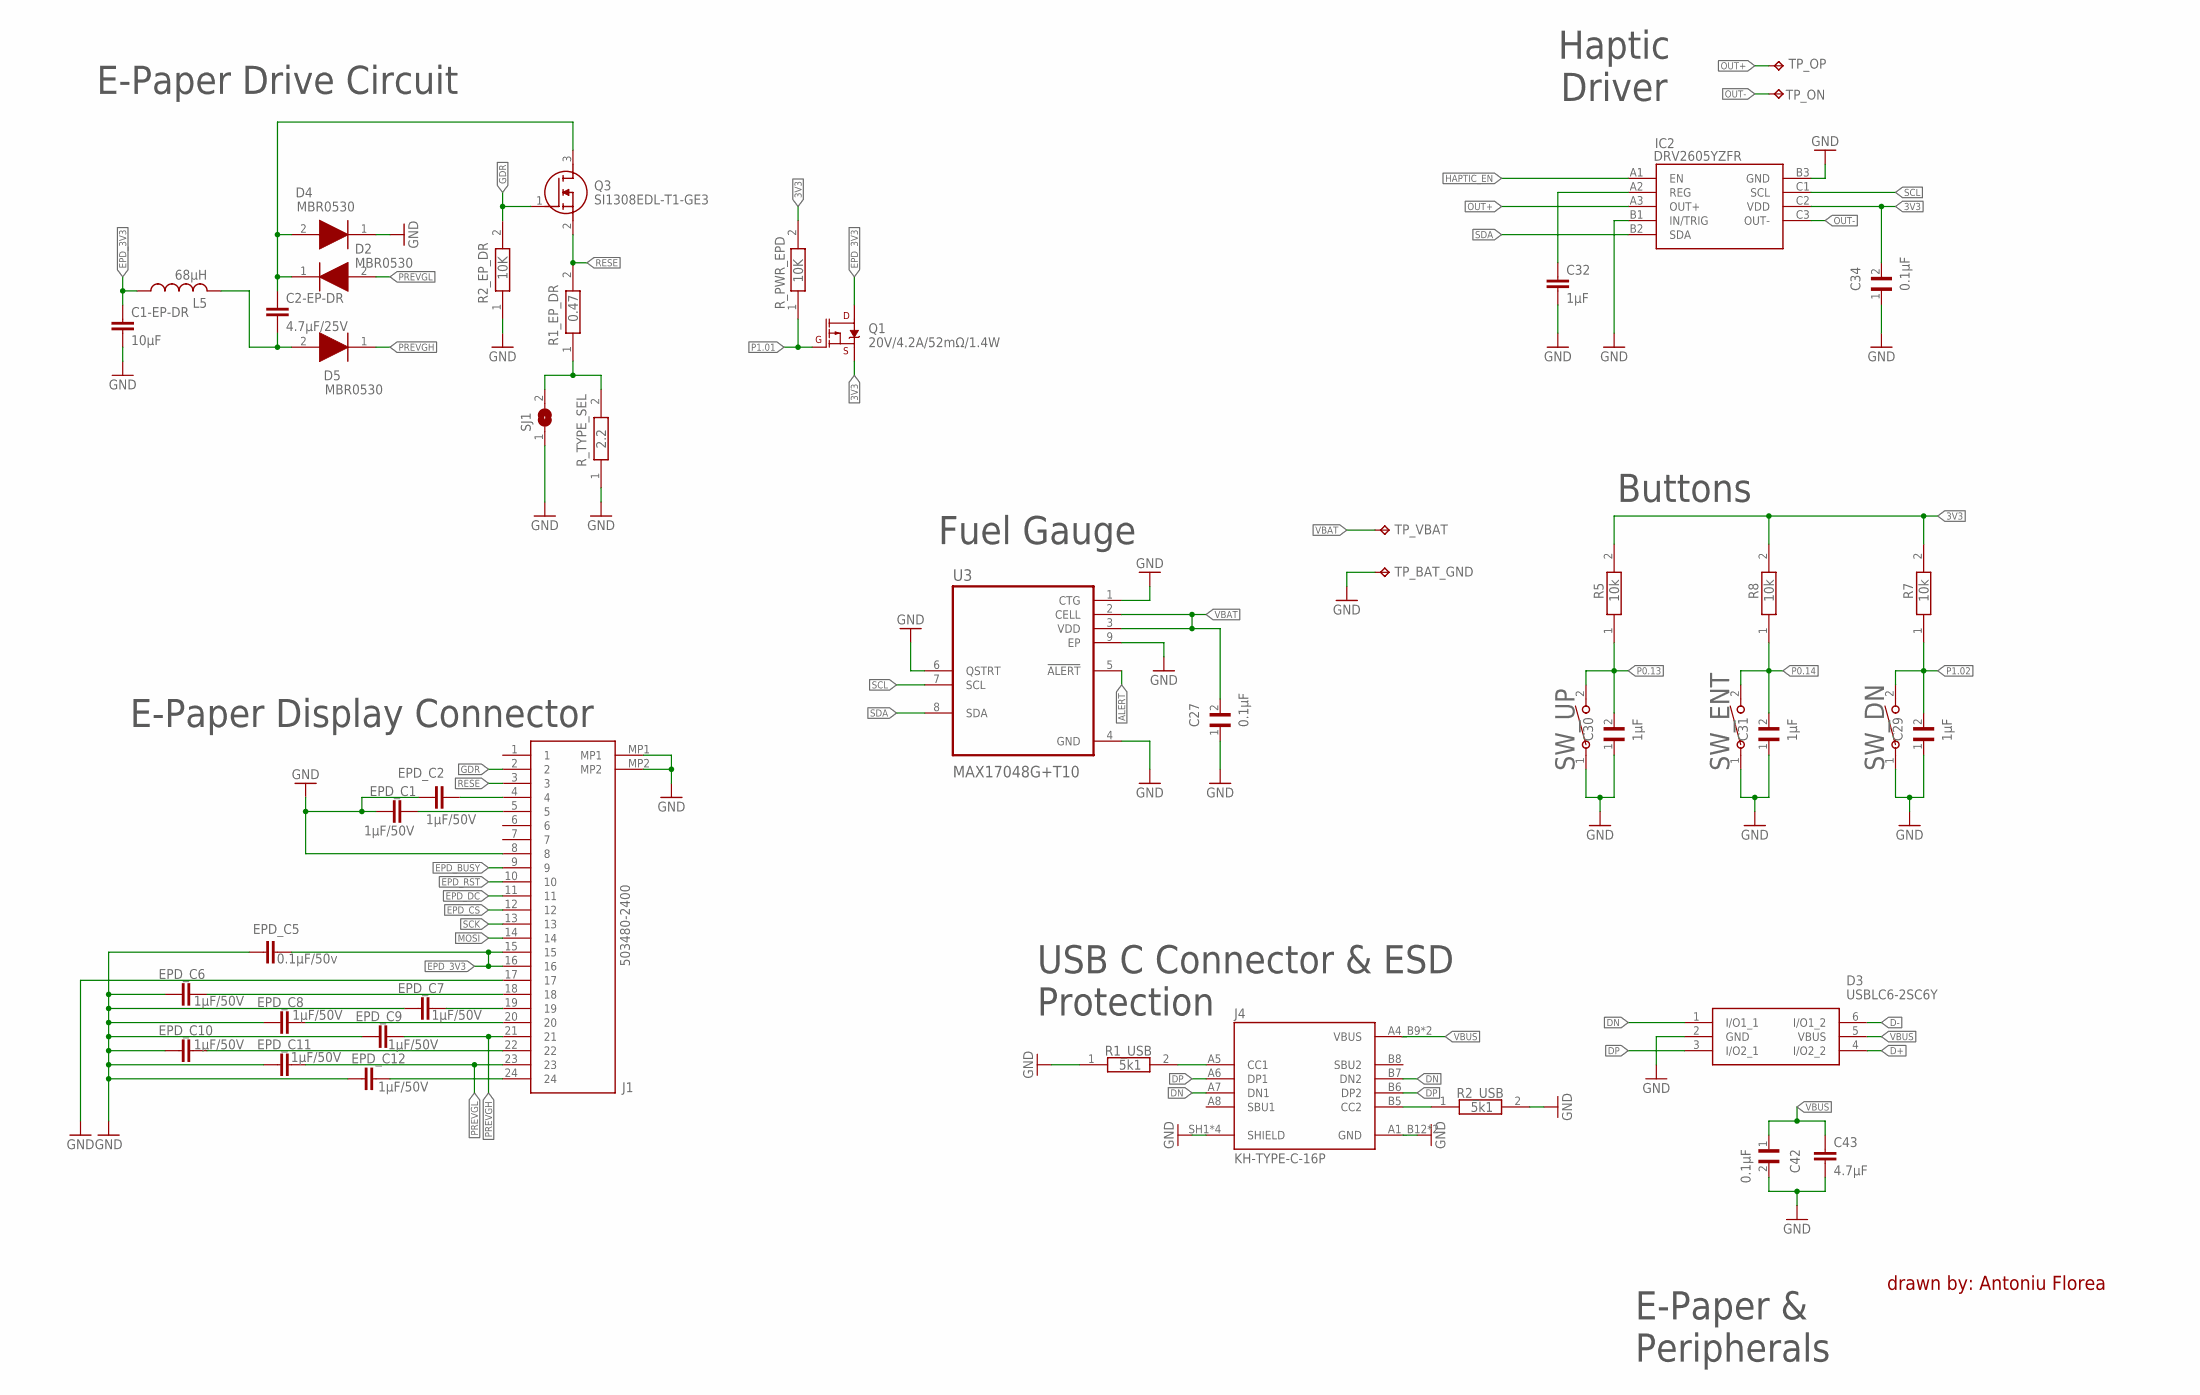
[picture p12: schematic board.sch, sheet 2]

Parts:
C1-EP-DR: 10μF; NORDIC_NRF_3_RESC0402_L
C2-EP-DR: 4.7μF/25V; NORDIC_NRF_3_RESC0402_L
C27, C34, C42: 0.1μF; GRM011R60J152KE01L_2_CAPC0201X13N
C29, C30, C31: 1μF; GRM011R60J152KE01L_2_CAPC0201X13N
C32: 1μF; NORDIC_NRF_3_RESC0402_L
C43: 4.7μF; NORDIC_NRF_3_RESC0402_L
D2, D4, D5: MBR0530; ESP32_C6_LIBRARY_5_SOD3716X135N
D3: USBLC6-2SC6Y; ESP32_C6_LIBRARY_3_SOT95P280X145-6N
EPD_C1, EPD_C2, EPD_C6, EPD_C7, EPD_C8, EPD_C9, EPD_C10, EPD_C11, EPD_C12: 1μF/50V; NORDIC_NRF_3_RESC0402_L
EPD_C5: 0.1μF/50v; NORDIC_NRF_3_RESC0201_L
IC2: DRV2605YZFR; DRV2605YZFR_BGA9C50P3X3_144X144X62
J1: 503480-2400; 503480-2400_5034802400
J4: KH-TYPE-C-16P; KH-TYPE-C-16P_KINGHELM_KH-TYPE-C-16P
L5: 68μH; NORDIC_NRF_2_RESC0402_L
Q1: 20V/4.2A/52mΩ/1.4W; ESP32_C6_LIBRARY_4_ESP32_C6_LIBRARY_4_ESP32_C6_LIBRARY_4_ES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
Q3: SI1308EDL-T1-GE3; ESP32_C6_LIBRARY_6_SOT65P210X110-3N
R1_EP_DR: 0.47; CPF0201D7K68C1_0201
R1_USB, R2_USB: 5k1; ERA-1AEB3401C_0201
R2_EP_DR: 10K; CPF0201D7K68C1_0201
R5, R7, R8: 10k; CPF0201D7K68C1_0201
R_PWR_EPD: 10K; CPF0201D7K68C1_0201
R_TYPE_SEL: 2.2; CPF0201D7K68C1_0201
SJ1: ESP32_C6_LIBRARY_7_JUMPER_SJ
SW_DN: 2025-10-22_07-23-44_LIBRARY_EVP-AKE31ASW_EVP-AKE3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; 2025-10-22_07-23-44_LIBRARY_SW_EVP-AKE31A_PAN
SW_ENT: 2025-10-22_07-23-44_LIBRARY_EVP-AKE31ASW_EVP-AKE3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; 2025-10-22_07-23-44_LIBRARY_SW_EVP-AKE31A_PAN
SW_UP: 2025-10-22_07-23-44_LIBRARY_EVP-AKE31ASW_EVP-AKE3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; 2025-10-22_07-23-44_LIBRARY_SW_EVP-AKE31A_PAN
TP_BAT_GND: HECTOR_WATCH_1_TPTP20R; HECTOR_WATCH_1_TP20R
TP_ON: HECTOR_WATCH_1_TPTP20R; HECTOR_WATCH_1_TP20R
TP_OP: HECTOR_WATCH_1_TPTP20R; HECTOR_WATCH_1_TP20R
TP_VBAT: HECTOR_WATCH_1_TPTP20R; HECTOR_WATCH_1_TP20R
U3: MAX17048G+T10; ESP32_C6_LIBRARY_SON50P200X200X80-9N

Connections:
3V3: C34.2, IC2.C2 (VDD), Q1.2 (S), R5.2, R7.2, R8.2, R_PWR_EPD.2; also elsewhere on the board
ALERT: U3.5 (!ALERT); also elsewhere on the board
D+: D3.4 (I/O2_2); also elsewhere on the board
D-: D3.6 (I/O1_2); also elsewhere on the board
DN: D3.1 (I/O1_1), J4.A7 (DN1), J4.B7 (DN2)
DP: D3.3 (I/O2_1), J4.A6 (DP1), J4.B6 (DP2)
EPD_3V3: C1-EP-DR.1, EPD_C5.2, J1.15, J1.16, L5.1, Q1.3 (D)
EPD_BUSY: J1.9; also elsewhere on the board
EPD_CS: J1.12; also elsewhere on the board
EPD_DC: J1.11; also elsewhere on the board
EPD_RST: J1.10; also elsewhere on the board
GDR: J1.2, Q3.1 (G), R2_EP_DR.2
GND: C1-EP-DR.2, C27.1, C29.1, C30.1, C31.1, C32.2, C34.1, C42.2, C43.2, D3.2 (GND), D4.1 (K), EPD_C1.2, EPD_C2.2, EPD_C5.1, EPD_C6.2, EPD_C7.2, EPD_C8.2, EPD_C9.2, EPD_C10.2, EPD_C11.2, EPD_C12.2, IC2.B1 (IN/TRIG), IC2.B3 (GND), J1.8, J1.17, J1.MP1, J1.MP2, J4.A1_B12 (GND), J4.A12_B1 (GND), J4.SH1 (SHIELD), J4.SH2 (SHIELD), J4.SH3 (SHIELD), J4.SH4 (SHIELD), R1_USB.1, R2_EP_DR.1, R2_USB.2, R_TYPE_SEL.1, SJ1.1, SW_DN.1, SW_ENT.1, SW_UP.1, TP_BAT_GND.TP, U3.1 (CTG), U3.4 (GND), U3.6 (QSTRT), U3.9 (EP); also elsewhere on the board
HAPTIC_EN: IC2.A1 (EN); also elsewhere on the board
MOSI: J1.14; also elsewhere on the board
unnamed: C2-EP-DR.2, D5.2 (A), L5.2
unnamed: C2-EP-DR.1, D2.1 (K), D4.2 (A), Q3.3 (D)
unnamed: EPD_C2.1, J1.4
unnamed: R1_EP_DR.1, R_TYPE_SEL.2, SJ1.2
unnamed: C32.1, IC2.A2 (REG)
unnamed: EPD_C1.1, J1.5
unnamed: EPD_C6.1, J1.18
unnamed: EPD_C7.1, J1.19
unnamed: EPD_C8.1, J1.20
unnamed: J4.A5 (CC1), R1_USB.2
unnamed: EPD_C10.1, J1.22
unnamed: EPD_C12.1, J1.24
unnamed: J4.B5 (CC2), R2_USB.1
OUT+: IC2.A3 (OUT+), TP_OP.TP
OUT-: IC2.C3 (OUT-), TP_ON.TP
P0.13: C30.2, R5.1, SW_UP.2; also elsewhere on the board
P0.14: C31.2, R8.1, SW_ENT.2; also elsewhere on the board
P1.01: Q1.1 (G), R_PWR_EPD.1; also elsewhere on the board
P1.02: C29.2, R7.1, SW_DN.2; also elsewhere on the board
PREVGH: D5.1 (K), EPD_C9.1, J1.21
PREVGL: D2.2 (A), EPD_C11.1, J1.23
RESE: J1.3, Q3.2 (S), R1_EP_DR.2
SCK: J1.13; also elsewhere on the board
SCL: IC2.C1 (SCL), U3.7 (SCL); also elsewhere on the board
SDA: IC2.B2 (SDA), U3.8 (SDA); also elsewhere on the board
VBAT: C27.2, TP_VBAT.TP, U3.2 (CELL), U3.3 (VDD); also elsewhere on the board
VBUS: C42.1, C43.1, D3.5 (VBUS), J4.A4_B9 (VBUS), J4.A9_B4 (VBUS); also elsewhere on the board

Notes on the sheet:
E-Paper Drive Circuit
Haptic Driver
E-Paper Display Connector
Fuel Gauge
Buttons
USB C Connector & ESD Protection
E-Paper & Peripherals
drawn by: Antoniu Florea

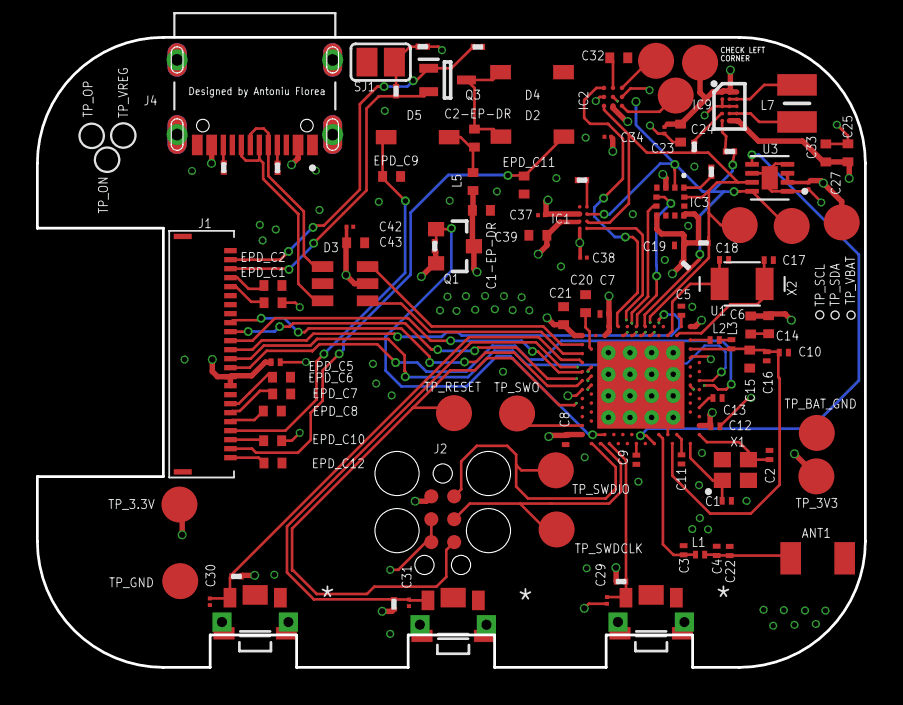
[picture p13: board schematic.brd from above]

Board: 4 copper layers, 46.0 x 35.0 mm, 105 parts (0 on the bottom side), 70 nets.

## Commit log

2026-04-21 Added updated schematic and design.
    Added .sch, .brd and .pdf of schematic fixing issues.
    [board.sch, schematic.brd]
2026-04-21 Updated manufacturing after changes to board.
2026-04-21 Added renders of final product and board.

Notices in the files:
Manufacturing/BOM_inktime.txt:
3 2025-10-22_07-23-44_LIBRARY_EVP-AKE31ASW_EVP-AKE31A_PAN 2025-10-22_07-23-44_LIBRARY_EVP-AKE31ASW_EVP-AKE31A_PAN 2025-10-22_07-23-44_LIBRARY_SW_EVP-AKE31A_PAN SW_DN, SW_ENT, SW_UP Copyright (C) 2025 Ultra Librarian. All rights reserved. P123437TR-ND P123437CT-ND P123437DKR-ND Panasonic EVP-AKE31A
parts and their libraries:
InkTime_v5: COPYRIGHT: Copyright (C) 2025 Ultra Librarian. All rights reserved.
